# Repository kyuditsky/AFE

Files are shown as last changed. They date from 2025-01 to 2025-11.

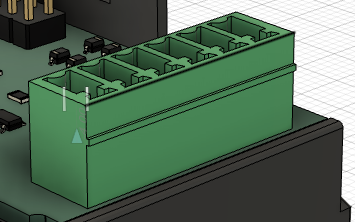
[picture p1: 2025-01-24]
images/Fusion/connector 2025-01-24 at 3.18.13 PM.png

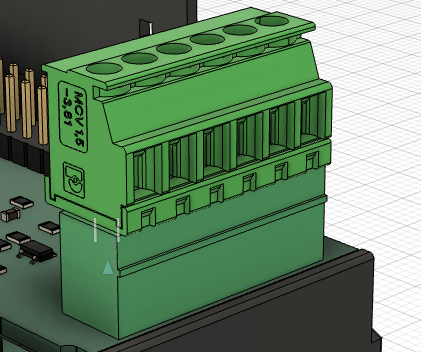
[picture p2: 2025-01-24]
images/Fusion/connector 2025-01-24 at 3.18.21 PM.png

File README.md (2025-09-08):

AFE 230V 16A

Phoenix Contact
BC Modular Housing

AFE 230v_16a buildnotes
addendums at bottom

1/14/25

***

https://media.digikey.com/pdf/data%20sheets/phoenix%20contact%20pdfs/bc_series_installation_component_housing.pdf

***

***

https://github.com/erichelgeson/Kicad-STM32
add legacy symbols:
symbol editor > File > import

manage symbols > migrate

***

BC71,6 OT-U11

i/o
---
MSTBVA_2,5_2-G-5,08		#LPC 2,5/2-ST-5,08	plug 16A / 320V
				#1792757		12A / will actually fit
				#MVSTBW 2,5/ 2-ST-5,08
j1	VO_pn
j2	K_io
j3	I_pn

MCV_1,5_6-G-3.81
j4	DGND
	3v3
	A0
	A1
	A2
	D0

footprints
TSOT-23-5	opamps
SOT-23		regulator
SOIC-7		optocoupler
SOIC-8		currentsensee

A5?		#A2
3v3in?

***
1/15/25
Blackpill STM32 will be on separate daughterboard

added HBUS connector to schema

***
HBUS-B SET BK - Protective cap
2278173
***

Spec:
Contact 1..4	power
contact 5..16	signal
Air clearances and creepage distances
... to the DIN rail At least 0.23 mm
... between one another At least 0.13 mm
... between power and signal At least 0.8 mm
Current carrying capacity for each contact
3 A, maximum total current 25 A

***
1/16/25

generated BOM from schema
refined layout and i/o port locations

request to swap A2 to A0 and slide down accordingly
	basically current on the left, voltage on right
	of J4

***
1/23/25

Housing:

HBUS 71,6-16P-1S BK - DIN rail bus connectors	2896296		#digikey 10 instock - 33.54

full set
BC 71,6-SKT-U11-7035+4SPTA6 - Housing set	1456985		#larger space on PCB2-8
								#11mm connector space on PCB1

Base:
BC 71,6 UT HBUS BK - Mounting base housing	2896267		#8.53

upperhousing UT11
BC 71,6 OT U11 KMGY - Upper housing part	2896050		#5.66

housing cover:
BC 71,6 DKL S TRANS - Housing cover		2896128		#4.93

inter-PCB connection:

ESW-106-12-G-D		6 pos, 11.05mm above pcb, gold plated, double row (12pos total)
			2.54 pitch, THT

2.54 pin header		underside of connecting pcb
			
	11.05mm + 2.54mm = 	13.59mm stack height
				perfect stack from pcb1 to pcb4

***
1/24/25

added copper pours from current i/o to U5

blackpill pinout in PCBnew appears incorrect to documentation

footprint matches:
	https://uglyduck.vajn.icu/STM32_Pills/BlackPill_STM32F103_Pinout.jpg

current blackpill:
	https://cdn-shop.adafruit.com/970x728/4877-03.jpg

updated with:
	https://github.com/MSZ98/Blackpill-KiCad-library

STEP files imported into Fusion

	MCV_1,5_6-G-3.81 	&	MCVR 1,5/ 6-ST-3,81
	1803468				1827169
		will not work, move socket towards pcb edge

	MSTBVA_2,5_2-G-5,08	&	MVSTBW 2,5/ 2-ST-5,08
	1755736				1792757
		will NOT work
		connectors should rotate
		and new connector should be chosen

Fillets on main PCB edges are only needed if filler plugs are to be used

SPTAF 1/ 5-3, 5-IL	supplied with housing kit, 11mm deep
	16A 160V

1862275
SPTAF 1/ 2-5,0-IL	2 terminal
	16A 320V	made to order	in stock at mouser
			IL vs EL

SPTAF 1/ 4-5,0-EL	4 terminal	#use 6 terminal for signal i/o
1862437			

AC inputs should be at least 2.5mm wire

***
https://electronics.stackexchange.com/questions/645255/4-layer-board-clearance-and-stack-up-for-230v

creepage / clearance

remove gnd plane from around I_inputs & Vp/n

***
1/27/25

SPTAF 1/ 6-5,0-EL
1862453

2202302 upper housing 11,11,22,00	restricted availability

in order to use SPTA-THR 2,5/ 6-5,0 P26		#for 12 awg wire AC inputs
need to swtich to UT22 upperhousing

1071206
SPTA-THR 1,5/ 6-5,08 R56	#might work, wire size 16awg
				#nonstocked at mouser
				#instock at digikey

***
02/02/25

Mouser Order sent			order#273566739

ordered two MKDSN 1.5/2-HT		1985849		rated 13A/320v
	for Ki/o
AC inputs: MKDSN 2.5/3-5.08-BK		1800882		
	(2.5/6 out of stock)
Signal Out: MKDS 1.5/6			1715190

********

02/06/25

revisiting pcb2-8
	& headers between
	see 01/23/25		#ESW-106-12-G-D

JLCPCB standard pcb thickness = 1.6mm

space between each:

pcb1-2	3,55mm
pcb2-3	3,45
pcb3-4	3,45
pcb4-5	3.45		#if blackpill is socketed, void pcb5-8
pcb5-6	3,45
pcb6-7	0,95
pcb7-8	-0.3		#pcb7&8 cannot co-exist
pcb8-9	1.25		#pcb9 replaces fitted cover

>>>pcb1 edge dimensions are incorrect
	edge cutouts in middle are too deep
	HBUS connector is in the wrong spot
>>fixed hbus placement
	did not change edgecuts
	current edge cut and drawing differ 0,45mm	
		#radius of curve 1,2mm but edges are 0,75mm offset
		#hbus location callout uses the 0,75mm line

considering shifting intrapcb connector to the left	#implemented
	reasoning: allows for pcb 2 to be installed (cutout is close to mounting fin ~1.5mm)

****
02/16/25

added pcb5-7 with kludge and copper pours
added kludge to other pcbs

added silkscreen on pcb9

****

02/27/25

PCBs arrived, Parts arrived
putting it together:

pcb8 does not fully lock into bottom case
	top base needs a support remove as well
	*use pcb7 instead (may still need to remove support
	pcb8 gnd plane net is wrong

overall, edgecuts are correct

c1-2 are 0402?		#my bad
	footprint is 0603

the intrapcb connectors looks good
make cutout in pcb2,3 larger, but fits for now

U4, solidstate relay, just barely fits under pcb2

typical female 2.54mm header, from pcb1 to pcb3, stacks directly underpcb3

	pcb3-pcb5 approximately the same thing
	could probably use pcb1, 3, & 5 for a 3 board arrangement

****
05/05/25 - meeting

issues soldering the ground plane pads - with thermal relief

plan to design to pick and place, still jlcpcb?
	mitigate some of the issues possibly due to soldering

testing feels like a waste of time, i dont always know what im looking at

dont have a good grasp of the details of the scope

single ended two op amps, gnd and point
	A0 and A1 subtract one from another to get ------

differential has 3 op amp
	does the subtraction

single
a0 ref to gnd
a1 ref to gnd
	note divider from 3V to GND to give 1.5v at input buffer

diff r19 r21 should be 500, r20 1k
r22 r23 dnp

everycircuit - simulator

testing setup >>
single ended (two opamp)
	wavegen 1 & gnd to V0p & V0n
	scope 1+ to A0			1+ 
	scope 1- to A1			scope 1- to dgnd
	3v3V+ to 3v3
	gnd to DGND
waveform passed through without power to board
	1.5v observed at r35/r36

differential
	wavegen 1 & gnd to V0p & V0n
	scope 1+ to A0
	scope 1- to dgnd
	3v3V+ to 3v3
	gnd to DGND
	
	0.6v observed at r35/r36
***	
	r22/r23 should be DNP
	r19/r21 should be 500ohm

****
updated guidance:
Focus on single ended:

	two sides are separate paths, test 1 path at a time
	
	V0p - wave to A0 - scope
	scope1- to dgnd

	V0n - wave to A1 - scope
	scope1- to dgnd

	(need to check for 1.5V at r15/r17; r16/18)

07/09/25

differential board, 3 opamps
	depopped r22, r21
	lifted a trace near r22, 
		determined iron too hot with narrower tip

Lifted R19 pads while desoldering
	buss wired from R20 to U1-4 & R22
		cut old R22 trace to A0
		R19 is now on R22 pads
		replaced to 510ohm
R21 now 510ohm
R20 in place at 1k

hot glue placed over cut A0 trace
	(exposed gnd plane)

*******
08/13/25 10:00a

identify and order just the differential parts
	to be tested via V0/V1_sense on HBUS footprint
	using the digilent waveform gen

initial DNP:	
	r1-12 	voltage dividers 
	d1-4	zener diodes
	c1 c2	capacitors	sized up to 0603

V0_sense starts: 	
	r13 	499k ohm 	#consider a 0ohm resistor
	c1	1nf
	r15 	20k (to 3vREF)	#Voltage divider to non-inverting input U1
	r17	20k (to gnd)
	r19	510		#feedback R
	
	r24	1k		#buffer to non-inverting U3
	r27	1k		#buffer to 1.5vREF	(r35&r36 20k divider)

V1_sense starts:
	r14 	499k ohm 	#consider a 0ohm resistor
	c2	1nf
	r16 	20k (to 3vREF)	#Voltage divider to non-inverting input U2
	r18	20k (to gnd)
	r21	510		#feedback R
	
	r25	1k		#buffer to inverting U3
	r26	1k		#U3 feedback

common components:

	U1-3	AD8528		#opamps		TSOT23-5
	d1-4	pdz36b		#36v zener diodes, order but dnp

	r20	1k		#ties both sides together
	r35	20k		#1.5vREF
	r36	20k		#1.5vREF
	U7	REF3030		#3V regulator	SOT23

	r39	0		#gnd to dgnd
	C5,6,10	0.1uF		#filtercaps

notes:
	look at r20 net, should it be connected directly to output of u1
		#sent to nathan
		confirms r20 should bridge U1 out to U2 out
		updated PCBnew

	populate PCB a few components at a time & test
		looking at you 1.5vREF

AFE_230v_16a rev.2 aug25
	changelog
	
	changed r20 to u1 & u2 outputs
	added thermal relief to D1 D2 earth connections
	added thermal relief to I_p & I_n fill zones
	rotated U4 to keep traces on F.cu
	added AVDD indicator LEDs to main pcb

2pm
lets order the updated pcb and mouser components by end of day

	look into jlcpcb pick and place and smaller components (0402)

AFE_diff_schematic
	focus on just the differential section
		using 0402 components
****
new plan (again)
	we are ordering a new pcb (because of R20)
	pick and place the components on the new pcb (adjust footprints accordingly)
		keeping all R footprints for now, all C footprints are 0603

	U1-3, U6, LEDs, & R29 non- placeable
	D1-4 are extended ($3.00 per extended component type)
	U7 is extended, opted out

	ordering 5 boards, populating 2 ($0.75 more to populate 5 as opposed to 2)
				and rev1 single end works without revision
				but. lets keep some blank boards
	16.17 for pcb+pcba
	9.97 shipping
	-9.00 coupon
	total: 18.05

***

08/18/25
	plan to order female pin headers from Adafruit

	leave off R34 from auto-populating
		or add 0 ohm jumper

	need to organize spreadsheets better

****
09/08/25

ordered more microhook test leads

looking over mouser order

	AC signal inputs - 1
	Signal Outputs - 1
	K i/o - 2

	opamps - 10
	U4 Relay - 1
	U7 3v ref - 5
	U5 current sense - 2
	R29 big R - 4
	
	pcb4 elevated socket - 2

R20 could have been rerouted without a via to B.Cu
removed thermal relief from Ip,In

dont auto-populate r30,r31 (only pop for opamp current sensing with r29)

test before populating r1-12 (voltage dividers)

r13,14, r22,23 will need hand populating (extended componenets)
	#should not have popped r22,r23, but will test waveform thru A0,A1
5v,3v3 LED hand pop

header pins as needed
	V1/V0 test points
	DGND > D0 header
		dgnd, 3v, A0,A1,A2,D0

3v3, 5v LED test good

3v3 supply, no opamps
	3.317v at 3v3
	2.997v at 3vref
	1.483v at 1.5vref

#same divider but different nets?
#1.5vref and r15/r17 & r16/r18

power looks good, continueing to add opamps

Should not have popped r22,r23 for differential setup, but will test waveform thru A0,A1
	V0_sense thru to A0
	V1_sense thru to A1
		both test good without power to board, no offset

		with 3v3 power to board, look good, adds a 1.46v(A0) & 1.47v(A1) offset
			with or without waveform input (5v amplitude)
			scope range 1v/div

going to remove r22,r23
	r22,23 depopped without trouble

3v3 supply, opamps installed
r27, 1.5vref = 1.497v
3v0ref = 3.0v
3v3 = 3.317v
1.5vref = 1.497v (r35/r36)

power still looks good

3v3 to board

W1 to V0_sense
W2 to V1_sense

1+ to A0
1- to dgnd

no longer the 1.5v offset
	output (A0) looks promising, especially with Sine wave inputs
	scope range needs to be dialed down to 100mV/div or less

can add 
	Vin dividers (r1-12)
	input/signal I/O
	blackpill header
	Ki/o relay
& option for either 
		current sense IC (depop r30,31)
		or R29 & opamp

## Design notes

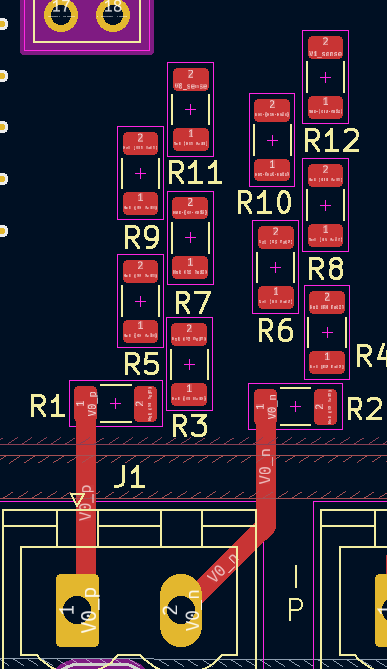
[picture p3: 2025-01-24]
images/screenshots/Screenshot 2025-01-22 at 2.59.26 PM.png

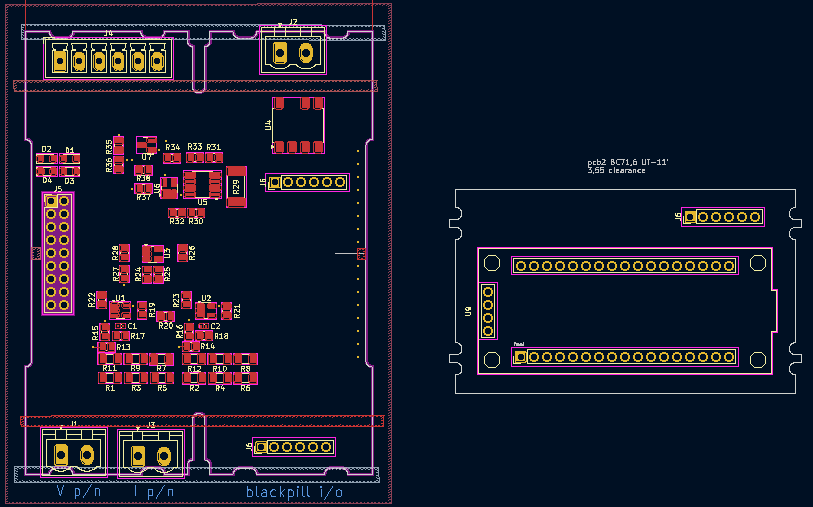
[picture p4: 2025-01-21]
images/adjust_layout_2025-01-21 at 1.56.01 PM.png

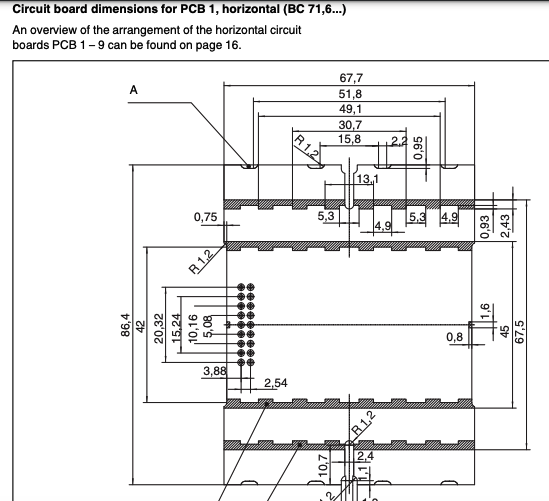
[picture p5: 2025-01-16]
images/HBUS_/Screenshot 2025-01-16 at 11.58.03 AM.png

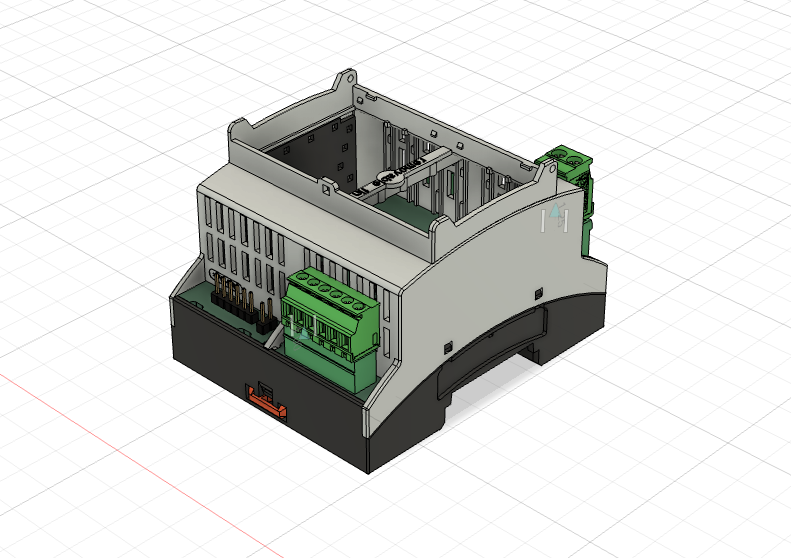
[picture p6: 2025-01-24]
images/Fusion/wide 2025-01-24 at 4.25.02 PM.png

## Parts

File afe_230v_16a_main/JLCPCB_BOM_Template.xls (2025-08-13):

Comment | Designator | Footprint | JLCPCB Part#(optional)
100uF | C1 | CASE-B_3528 | C16133
100nF | C2, C9, C10 | 0603 | C14663
300KΩ | R4, R7 | 0603 | C23024
15KΩ | R5, R6 | 0603_R | C22809
100KΩ | R1, R3 | 0603_R | C25803
10uF | C3-5 | 1206_C | C13585
100Ω | R2 | 0603_R | C22775
1N4148WS | D1 | SOD-323 | C2128
LM358DR2G | U1 | SOIC-8_150mil | C7950
HT7550-1 | VR1 | SOT-89(SOT-89-3) | C16106

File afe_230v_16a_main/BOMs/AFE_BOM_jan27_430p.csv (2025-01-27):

AFE_230V_16A
Mouser # | Mfr. # | Manufacturer | Customer # | Description | RoHS | Lifecycle | Order Qty. | Price (USD) | Ext.: (USD)
584-AD8538AUJZ-R7 | AD8538AUJZ-REEL7 | Analog Devices Inc. | AFE_U1-3,6 | Precision Amplifiers ingle Low Power AutoZero Amp | RoHS Compliant |  | 6 | $1.99 | $7.96
250-711ELCTR25ABT | ACS711ELCTR-25AB-T | Allegro MicroSystems | afe_U5 | Board Mount Current Sensors CURRENT SENSOR WITH OVERCURRENT FAULT OUTPUT | RoHS Compliant By Exemption |  | 1 | $1.54 | $1.54
595-REF3030AIDBZR | REF3030AIDBZR | Texas Instruments | afe_U7 | Voltage References 3.0V 50ppm/DegC 50uA SOT23-3 Series A 595-REF3030AIDBZT | RoHS Compliant |  | 2 | $1.02 | $1.02
769-AQH3223A | AQH3223A | Panasonic | afe_U4 | Solid State Relays - PCB Mount AC 600 V 1.2 A Non- Zero Cross | RoHS Compliant |  | 2 | $1.94 | $1.94
187-CL05C102JB51PNC | CL05C102JB51PNC | Samsung Electro-Mechanics | afe_C1,2 | Multilayer Ceramic Capacitors MLCC - SMD/SMT 1nF C0G 50V 0402 Auto grade | RoHS Compliant | New Product | 4 | $0.10 | $0.20
771-PDZ36B-T/R | PDZ36B,115 | Nexperia | afe_D1-4 ! | Zener Diodes PDZ36B/SOD323/SOD2 | RoHS Compliant |  | 8 | $0.15 | $0.60
652-CHP1206AFX-6803L | CHP1206AFX-6803ELF | Bourns | afe_r1-12 | Thick Film Resistors - SMD ResHighPowerA 1206 68R 1% 3/4W TC100 | RoHS Compliant By Exemption |  | 24 | $0.202 | $2.42
667-ERJ-P06F4993V | ERJ-P06F4993V | Panasonic | afe_R13,14 | Thick Film Resistors - SMD 0805 499Kohms 0.5W 1% AEC-Q200 | RoHS Compliant By Exemption |  | 4 | $0.18 | $0.36
660-SG73P2ATTD2002F | SG73P2ATTD2002F | KOA Speer | afe_R15-18,35,36 | Thick Film Resistors - SMD 0.5W 20Kohm 1% AEC-Q200 | RoHS Compliant By Exemption |  | 12 | $0.17 | $1.02
71-RCC08050000Z0EA | RCC08050000Z0EA | Vishay | afe_R38_dnp | Thick Film Resistors - SMD Zero ohm Jumper | RoHS Compliant By Exemption |  | 7 | $0.13 | $0.39
667-ERJ-P06F1001V | ERJ-P06F1001V | Panasonic | afe_R30-34,37 | Thick Film Resistors - SMD 0805 1Kohms 0.5W 1% AEC-Q200 | RoHS Compliant By Exemption |  | 12 | $0.062 | $0.74
667-ERJ-P06F33R2V | ERJ-P06F33R2V | Panasonic | afe_R22,23 | Thick Film Resistors - SMD 0805 33.2ohms 0.5W 1% AEC-Q200 | RoHS Compliant By Exemption |  | 4 | $0.18 | $0.36
 |  |  |  |  | RoHS Compliant
 |  |  |  |  | RoHS Compliant
279-TLRP3A20WR005FTE | TLRP3A20WR005FTE | TE Connectivity | afe_R29 | Current Sense Resistors - SMD TLRP 2512 2.0W R005 1% 75PPM 4K RL |  |  | 1 | $0.66 | $0.66
651-2896050 | 2896050 | Phoenix Contact |  | Upper housing |  |  | 2
651-2896267 | 2896267 | Phoenix Contact |  | Housing base |  |  | 2
651-2896128 | 2896128 | Phoenix Contact |  | Housing cover |  |  | 1
651-2896209 | 2896209 | Phoenix Contact |  | Filler Plug |  |  | 2
200-ESW10612GD | ESW-106-12-G-D | Samtec | afe_pcb4_conn | Elevated socket strip |  |  | 2
855-M20-9774046 | M20-9774046 | Darwin |  | Pin header strip |  |  | 4
649-76308-120LF | 76308-120LF | Amphenol FCI |  | 1x20 pinheaded socket (black pill) |  |  | 5
81-GCM188R71C104KA7J | GCM188R71C104KA37J | Murata | afe_C4-10 | 0.1uf filter caps |  |  | 8
651-1800882 | 1800882 |  | AC input_alts | MKDSN 2,5/ 3-5,08 |  |  | 4
651-1989405 | 1989405 |  | AC inputs | MKDSN 2,5/ 6-5,08 |  |  | 0
651-1715190 | 1715190 |  | Signal | MKDS 1,5/ 6 |  |  | 2
604-APT2012LZGCK | APT2012LZGCK |  | afe_led1,2 | LED |  |  | 4
279-CRG0805J2K2 | CRG0805J2K2 |  | afe_led_r | LED_r |  |  | 4

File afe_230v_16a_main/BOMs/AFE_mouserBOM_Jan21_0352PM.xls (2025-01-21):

AFE_230V_16A
Mouser # | Mfr. # | Manufacturer | Customer # | Description | RoHS | Lifecycle | Order Qty. | Price (USD) | Ext.: (USD)
584-AD8538AUJZ-R7 | AD8538AUJZ-REEL7 | Analog Devices Inc. | AFE_U1-3,6 | Precision Amplifiers ingle Low Power AutoZero Amp | RoHS Compliant |  | 4 | $1.99 | $7.96
250-711ELCTR25ABT | ACS711ELCTR-25AB-T | Allegro MicroSystems | afe_U5 | Board Mount Current Sensors CURRENT SENSOR WITH OVERCURRENT FAULT OUTPUT | RoHS Compliant By Exemption |  | 1 | $1.54 | $1.54
595-REF3030AIDBZR | REF3030AIDBZR | Texas Instruments | afe_U7 | Voltage References 3.0V 50ppm/DegC 50uA SOT23-3 Series A 595-REF3030AIDBZT | RoHS Compliant |  | 1 | $1.02 | $1.02
769-AQH3223A | AQH3223A | Panasonic | afe_U4 | Solid State Relays - PCB Mount AC 600 V 1.2 A Non- Zero Cross | RoHS Compliant |  | 1 | $1.94 | $1.94
187-CL05C102JB51PNC | CL05C102JB51PNC | Samsung Electro-Mechanics | afe_C1,2 | Multilayer Ceramic Capacitors MLCC - SMD/SMT 1nF C0G 50V 0402 Auto grade | RoHS Compliant | New Product | 2 | $0.10 | $0.20
771-PDZ36B8115 | PDZ3.6B,115 | Nexperia | afe_D1-4_! | Zener Diodes PDZ3.6B/SOD323/SOD2 | RoHS Compliant |  | 4 | $0.10 | $0.40
771-PDZ36B-T/R | PDZ36B,115 | Nexperia | afe_D1-4 ! | Zener Diodes PDZ36B/SOD323/SOD2 | RoHS Compliant |  | 4 | $0.15 | $0.60
652-CHP1206AFX-6803L | CHP1206AFX-6803ELF | Bourns | afe_r1-12 | Thick Film Resistors - SMD ResHighPowerA 1206 68R 1% 3/4W TC100 | RoHS Compliant By Exemption |  | 12 | $0.202 | $2.42
667-ERJ-P06F4993V | ERJ-P06F4993V | Panasonic | afe_R13,14 | Thick Film Resistors - SMD 0805 499Kohms 0.5W 1% AEC-Q200 | RoHS Compliant By Exemption |  | 2 | $0.18 | $0.36
660-SG73P2ATTD2002F | SG73P2ATTD2002F | KOA Speer | afe_R15-18,35,36 | Thick Film Resistors - SMD 0.5W 20Kohm 1% AEC-Q200 | RoHS Compliant By Exemption |  | 6 | $0.17 | $1.02
71-RCC08050000Z0EA | RCC08050000Z0EA | Vishay | afe_R38_dnp | Thick Film Resistors - SMD Zero ohm Jumper | RoHS Compliant By Exemption |  | 3 | $0.13 | $0.39
667-ERJ-P06F1001V | ERJ-P06F1001V | Panasonic | afe_R30-34,37 | Thick Film Resistors - SMD 0805 1Kohms 0.5W 1% AEC-Q200 | RoHS Compliant By Exemption |  | 12 | $0.062 | $0.74
667-ERJ-P06F33R2V | ERJ-P06F33R2V | Panasonic | afe_R22,23 | Thick Film Resistors - SMD 0805 33.2ohms 0.5W 1% AEC-Q200 | RoHS Compliant By Exemption |  | 2 | $0.18 | $0.36
651-1755736 | 1755736 | Phoenix Contact | afe_J1-3 | Pluggable Terminal Blocks 2 Pos 5.08mm pitch Through Hole Header | RoHS Compliant |  | 3 | $0.64 | $1.92
651-1803468 | 1803468 | Phoenix Contact | afe_J4 | Pluggable Terminal Blocks 6 Pos 3.81mm pitch Through Hole Header | RoHS Compliant |  | 1 | $2.39 | $2.39
279-TLRP3A20WR005FTE | TLRP3A20WR005FTE | TE Connectivity | afe_R29 | Current Sense Resistors - SMD TLRP 2512 2.0W R005 1% 75PPM 4K RL |  |  | 1 | $0.66 | $0.66

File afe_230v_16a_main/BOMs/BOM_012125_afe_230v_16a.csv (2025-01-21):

Reference | Value | Datasheet | Footprint | Qty | DNP
C1,C2 | 1nF | ~ | Capacitor_SMD:C_0402_1005Metric | 2
J1,J2,J3 | MSTBVA_2,5_2-G-5,08 |  |  | 3
D1,D2,D3,D4 | PDZ36B | ~ | Diode_SMD:D_SOD-323F | 4
J4 | MCV 1,5/ 6-G-3,81 | ~ | Connector_Phoenix_MC:PhoenixContact_MCV_1,5_6-G-3.81_1x06_P3.81mm_Vertical | 1
J5 |  | HBUS 71,6-16P-1S BK / 2896296 | Connector_PinHeader_2.54mm:PinHeader_2x09_P2.54mm_Vertical | 1
P1 | 06-14-03_rectifier |  |  | 1
R1,R2,R3,R4,R5,R6,R7,R8,R9,R10,R11,R12 | 680K | ~ | Resistor_SMD:R_1206_3216Metric | 12
R13,R14 | 499K | ~ | Resistor_SMD:R_0805_2012Metric | 2
R15,R16,R17,R18,R35,R36 | 20K | ~ | Resistor_SMD:R_0805_2012Metric | 6
R19,R21 | 0K | ~ | Resistor_SMD:R_0805_2012Metric | 2
R20,R24,R25,R26,R27,R28 | 1K_dnp | ~ | Resistor_SMD:R_0805_2012Metric | 6 | DNP
R22,R23 | 33R2 | ~ | Resistor_SMD:R_0805_2012Metric | 2
R29 | 0R005 | ~ | Resistor_SMD:R_2512_6332Metric_Pad1.40x3.35mm_HandSolder | 1
R30,R31,R32,R33,R34,R37 | 1KR | ~ | Resistor_SMD:R_0805_2012Metric | 6
R38 | 0K_dnp | ~ | Resistor_SMD:R_0805_2012Metric | 1 | DNP
U1 | AD8538 | https://www.analog.com/media/en/technical-documentation/data-sheets/AD8538_8539.pdf | Package_TO_SOT_SMD:TSOT-23-5 | 1
U2 | AD8538 | https://www.analog.com/media/en/technical-documentation/data-sheets/AD8538_8539.pdf | Package_TO_SOT_SMD:TSOT-23-5 | 1
U3,U6 | AD8538_dnp | https://www.analog.com/media/en/technical-documentation/data-sheets/AD8538_8539.pdf | Package_TO_SOT_SMD:TSOT-23-5 | 2 | DNP
U4 | AQH3223A | https://mediap.industry.panasonic.eu/assets/imported/industrial.panasonic.com/ac/cdn/e/control/relay/solid-state/catalog/semi_eng_aqh.pdf | Package_SO:SSO-7-8_6.4x9.78mm_P2.54mm | 1
U5 | ACS711xLCTR-25AB | http://www.allegromicro.com/~/Media/Files/Datasheets/ACS711-Datasheet.ashx | Package_SO:SOIC-8_3.9x4.9mm_P1.27mm | 1
U7 | REF3030 | http://www.ti.com/lit/ds/symlink/ref3033.pdf | Package_TO_SOT_SMD:SOT-23 | 1

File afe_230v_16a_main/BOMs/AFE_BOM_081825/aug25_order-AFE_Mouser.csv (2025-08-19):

AFE_230V_16A
Mouser # | Mfr. # | Manufacturer | Customer # | Qty. | Hand | JLC_mount | Description | RoHS | Lifecycle | Order Qty. | Price (USD) | Ext.: (USD)
584-AD8538AUJZ-R7 | AD8538AUJZ-REEL7 | Analog Devices Inc. | AFE_U1-3,6 | 10 |  |  | Precision Amplifiers ingle Low Power AutoZero Amp | RoHS Compliant |  | 6 | $1.99 | $7.96
250-711ELCTR25ABT | ACS711ELCTR-25AB-T | Allegro MicroSystems | afe_U5 | 2 |  |  | Board Mount Current Sensors CURRENT SENSOR WITH OVERCURRENT FAULT OUTPUT | RoHS Compliant By Exemption |  | 1 | $1.54 | $1.54
595-REF3030AIDBZR | REF3030AIDBZR | Texas Instruments | afe_U7 | 4 |  |  | Voltage References 3.0V 50ppm/DegC 50uA SOT23-3 Series A 595-REF3030AIDBZT | RoHS Compliant |  | 2 | $1.02 | $1.02
769-AQH3223A | AQH3223A | Panasonic | afe_U4 | 1 |  |  | Solid State Relays - PCB Mount AC 600 V 1.2 A Non- Zero Cross | RoHS Compliant |  | 2 | $1.94 | $1.94
187-CL05C102JB51PNC | CL05C102JB51PNC | Samsung Electro-Mechanics | afe_C1,2 | 0 |  | Y | Multilayer Ceramic Capacitors MLCC - SMD/SMT 1nF C0G 50V 0402 Auto grade | RoHS Compliant | New Product | 4 | $0.10 | $0.20
81-GCM188R71C104KA7J | GCM188R71C104KA37J | Murata | afe_C4-10 | 0 |  | Y | 0.1uf filter caps 0402 |  |  | 8
771-PDZ36B-T/R | PDZ36B,115 | Nexperia | afe_D1-4 ! | 8 |  | Y | Zener Diodes PDZ36B/SOD323/SOD2 | RoHS Compliant |  | 8 | $0.15 | $0.60
652-CHP1206AFX-6803L | CHP1206AFX-6803ELF | Bourns | afe_r1-12 | 30 |  |  | Thick Film Resistors - SMD ResHighPowerA 1206 68R 1% 3/4W TC100 | RoHS Compliant By Exemption |  | 24 | $0.20 | $2.42
667-ERJ-P06F4993V | ERJ-P06F4993V | Panasonic | afe_R13,14 | 10 |  |  | Thick Film Resistors - SMD 0805 499Kohms 0.5W 1% AEC-Q200 | RoHS Compliant By Exemption |  | 4 | $0.18 | $0.36
660-SG73P2ATTD2002F | SG73P2ATTD2002F | KOA Speer | afe_R15-18,35,36 | 0 | 18 | Y | Thick Film Resistors - SMD 0.5W 20Kohm 1% AEC-Q200 | RoHS Compliant By Exemption |  | 12 | $0.17 | $1.02
71-RCC08050000Z0EA | RCC08050000Z0EA | Vishay | afe_R38, R39 | 0 | 18 | Y | Thick Film Resistors - SMD Zero ohm Jumper | RoHS Compliant By Exemption |  | 7 | $0.13 | $0.39
667-ERJ-P06F1001V | ERJ-P06F1001V | Panasonic | afe_R30-34,37 | 0 | 18 | Y | Thick Film Resistors - SMD 0805 1Kohms 0.5W 1% AEC-Q200 | RoHS Compliant By Exemption |  | 12 | $0.06 | $0.74
667-ERJ-P06F33R2V | ERJ-P06F33R2V | Panasonic | afe_R22,23 | 6 |  |  | Thick Film Resistors - SMD 0805 33.2ohms 0.5W 1% AEC-Q200 | RoHS Compliant By Exemption |  | 4 | $0.18 | $0.36
 |  |  | R40,41 | 20 |  | Y | Thick Film Resistors - SMD 0805 2.2kohms | RoHS Compliant
 |  |  | R19,21 | 10 |  | Y | Thick Film Resistors - SMD 0805 510ohms
 |  |  |  |  |  |  |  | RoHS Compliant
279-TLRP3A20WR005FTE | TLRP3A20WR005FTE | TE Connectivity | afe_R29 | 4 |  |  | Current Sense Resistors - SMD TLRP 2512 2.0W R005 1% 75PPM 4K RL |  |  | 1 | $0.66 | $0.66
651-2896050 | 2896050 | Phoenix Contact |  | 0 |  |  | Upper housing |  |  | 2
651-2896267 | 2896267 | Phoenix Contact |  | 0 |  |  | Housing base |  |  | 2
651-2896128 | 2896128 | Phoenix Contact |  | 0 |  |  | Housing cover |  |  | 1
651-2896209 | 2896209 | Phoenix Contact |  | 0 |  |  | Filler Plug |  |  | 2
200-ESW10612GD | ESW-106-12-G-D | Samtec | afe_pcb4_conn | 4 |  |  | Elevated socket strip |  |  | 2
855-M20-9774046 | M20-9774046 | Darwin |  | 0 |  |  | Pin header strip |  |  | 4
649-76308-120LF | 76308-120LF | Amphenol FCI |  |  |  |  | Female header strip - 20 POS |  |  |  | 3.71
604-APT2012LZGCK | APT2012LZGCK |  | afe_led1,2 | 10 |  |  | Single Color LEDs Single Color LEDs 2.0X1.2MM LOW CRNT |  |  | 4
279-CRG0805J2K2 | CRG0805J2K2 |  | afe_led_r | 0 |  | Y | LED_r |  |  | 4
651-1800882 | 1800882 |  | AC input_alts | 4 |  |  | MKDSN 2,5/ 3-5,08 |  |  | 4
651-1989405 | 1989405 |  | AC inputs | 0 |  |  | MKDSN 2,5/ 6-5,08 |  |  | 0
651-1715190 | 1715190 |  | Signal | 2 |  |  | MKDS 1,5/ 6 |  |  | 2

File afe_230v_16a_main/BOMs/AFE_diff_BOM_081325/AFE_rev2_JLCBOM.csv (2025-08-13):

Value | Designator | Footprint | Jlcpcb part#
499kΩ | R13, R14 | 0805
1nF | C1, C2 | 0603
0.1uF | C4, C5, C6, C10 | 0603
680kΩ | R1-12 | 1206
20kΩ | R15, R16, R17, R18, R35, R36 | 0805
510Ω | R19, R21 | 0805
1kΩ | R20, R24-27, R30-34, R37 | 0805
PDZ36B | D1-4 | D_SOD-323
REF3030 | U7 | SOT23
0Ω | R38, R39 | 0805
2.2kΩ | R40, R41 | 0805

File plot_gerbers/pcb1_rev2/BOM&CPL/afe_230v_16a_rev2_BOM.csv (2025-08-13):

Designator | Val | Footprint
C1 | 1nF | C_0603_1608Metric_Pad1.08x0.95mm_HandSolder
C2 | 1nF | C_0603_1608Metric_Pad1.08x0.95mm_HandSolder
C4 | 0.1uF | C_0603_1608Metric_Pad1.08x0.95mm_HandSolder
C5 | 0.1uF | C_0603_1608Metric_Pad1.08x0.95mm_HandSolder
C6 | 0.1uF | C_0603_1608Metric_Pad1.08x0.95mm_HandSolder
C10 | 0.1uF | C_0603_1608Metric_Pad1.08x0.95mm_HandSolder
D1 | PDZ36B | D_SOD-323_HandSoldering
D2 | PDZ36B | D_SOD-323_HandSoldering
D3 | PDZ36B | D_SOD-323_HandSoldering
D4 | PDZ36B | D_SOD-323_HandSoldering
R15 | 20K | R_0805_2012Metric
R16 | 20K | R_0805_2012Metric
R17 | 20K | R_0805_2012Metric
R18 | 20K | R_0805_2012Metric
R19 | 510 | R_0805_2012Metric
R20 | 1K | R_0805_2012Metric
R21 | 510 | R_0805_2012Metric
R24 | 1K | R_0805_2012Metric
R25 | 1K | R_0805_2012Metric
R26 | 1K | R_0805_2012Metric
R27 | 1K | R_0805_2012Metric
R28 | 1K | R_0805_2012Metric
R30 | 1K | R_0805_2012Metric
R31 | 1K | R_0805_2012Metric
R32 | 1K | R_0805_2012Metric
R33 | 1K | R_0805_2012Metric
R34 | 1K | R_0805_2012Metric
R35 | 20K | R_0805_2012Metric
R36 | 20K | R_0805_2012Metric
R37 | 1K | R_0805_2012Metric
R38 | 0 | R_0805_2012Metric
R39 | 0 | R_0805_2012Metric
R40 | 2.2k | R_0805_2012Metric
R41 | 2.2k | R_0805_2012Metric
U7 | REF3030 | SOT-23

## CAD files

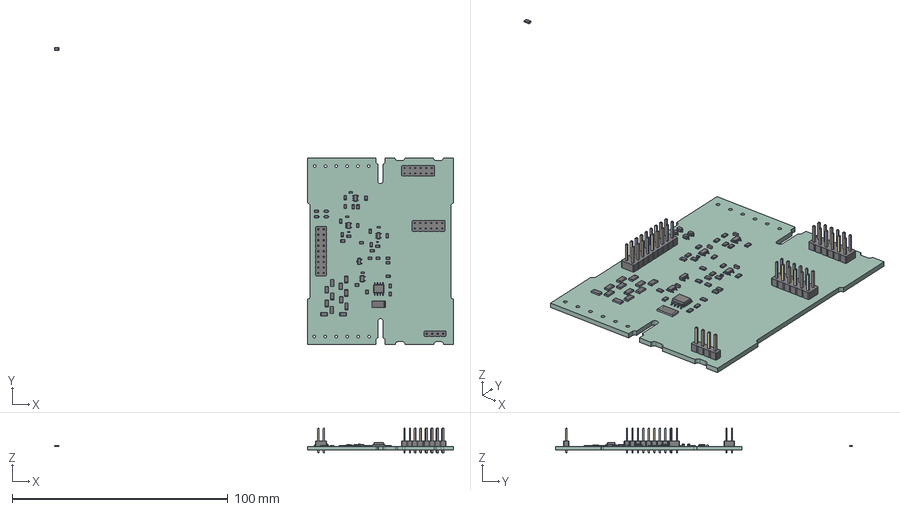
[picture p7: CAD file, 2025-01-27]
STEP/afe_230v_16a_6.step
184.9 x 137.5 x 11.5 mm
R_0805_2012Metric x 26
R_1206_3216Metric x 12
D_SOD_323 x 4
C_0402_1005Metric x 2
C_0603_1608Metric x 4
PinHeader_1x04_P254mm_Vertical
SOT_23
TSOT_23_5 x 4
SOIC_8_39x49mm_P127mm
PinHeader_2x06_P254mm_Vertical x 2
R_2512_6332Metric
PinHeader_2x09_P254mm_Vertical
_autosave-afe_230v_16a_PCB

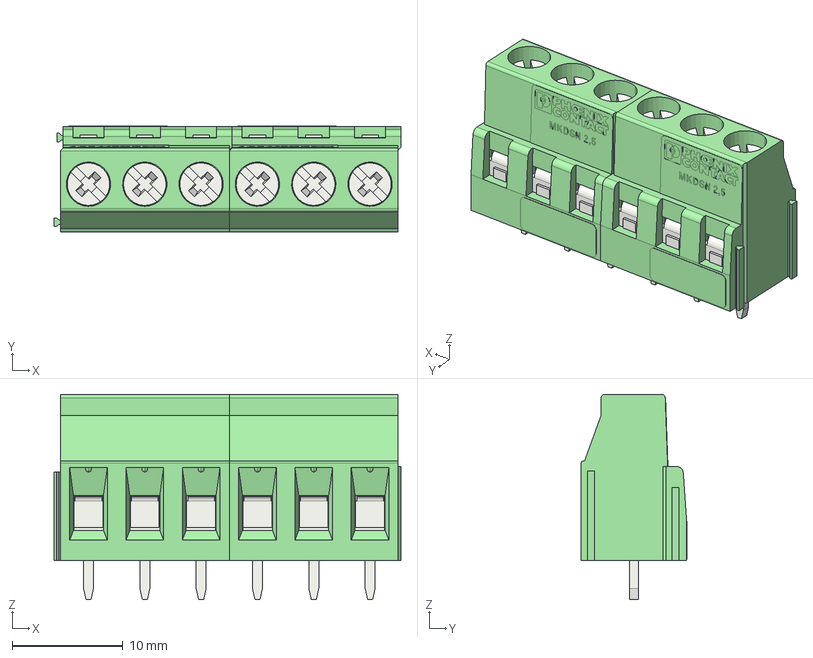
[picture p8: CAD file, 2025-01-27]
STEP/pxc_1989405_01_01_MKDSN-2-5-6-5-08_3D.stp
31.3 x 9.53 x 18.5 mm

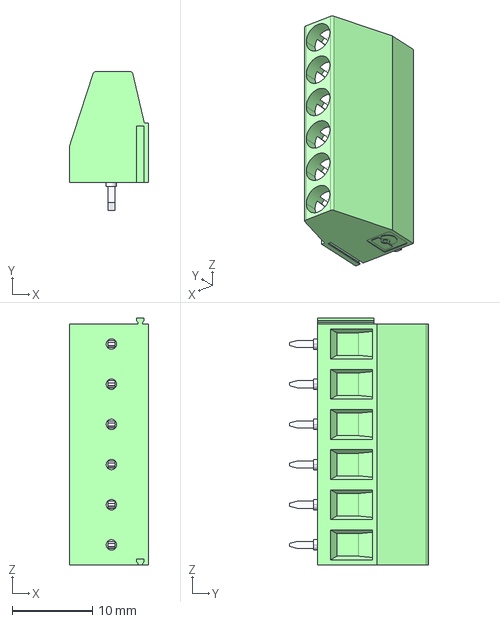
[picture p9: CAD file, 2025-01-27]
STEP/pxc_1715190_02_MKDS-1-5-6_3D.stp
9.80 x 17.3 x 30.7 mm

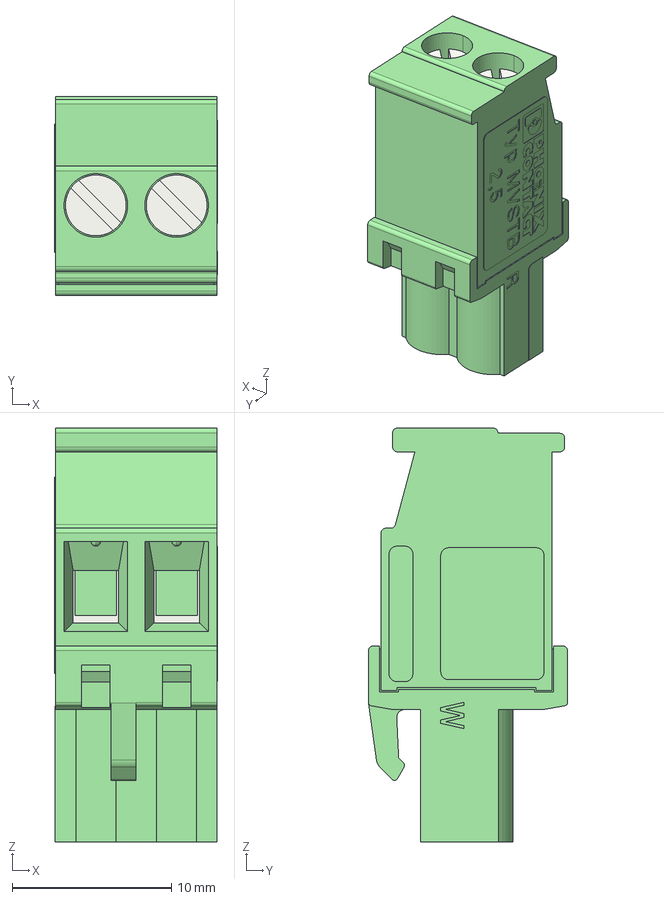
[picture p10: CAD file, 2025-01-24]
STEP/pxc_1792249_04_MVSTBR-2-5-2-ST-5-08_3D.stp
10.3 x 12.5 x 26.0 mm

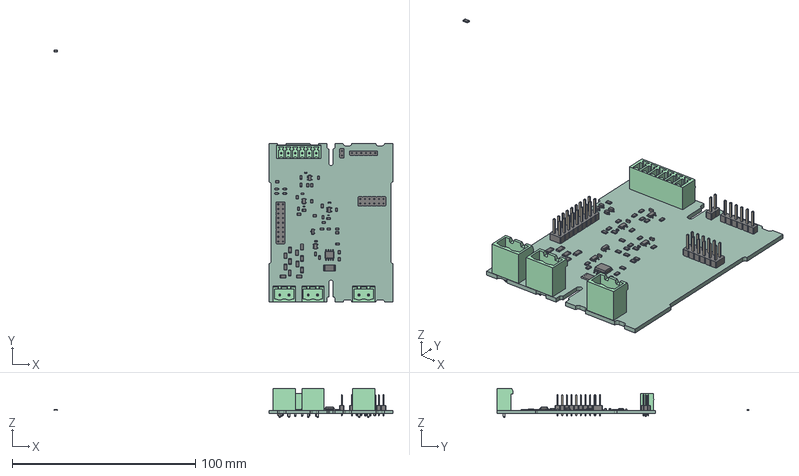
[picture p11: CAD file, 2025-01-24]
STEP/afe_230v_16a_2.step
184.9 x 137.5 x 16.0 mm
R_0805_2012Metric x 27
R_1206_3216Metric x 12
PinHeader_1x06_P254mm_Vertical
D_SOD_323 x 4
C_0402_1005Metric x 2
C_0603_1608Metric x 4
MSTBVA_01x02_G_5_08mm x 3
SOT_23
TSOT_23_5 x 4
SOIC_8_39x49mm_P127mm
MCV_01x06_G_3_81mm
PinHeader_2x06_P254mm_Vertical
R_2512_6332Metric
PinHeader_1x02_P254mm_Vertical
PinHeader_2x09_P254mm_Vertical
_autosave-afe_230v_16a_PCB

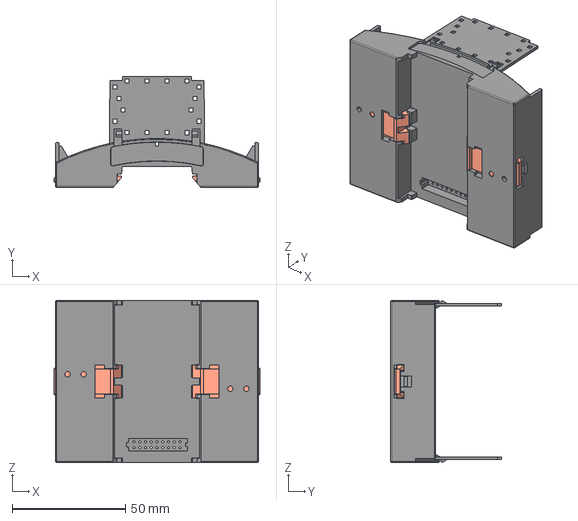
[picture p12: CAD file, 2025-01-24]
STEP/pxc_2896267_05_04_BC-71-6-UT-HBUS-BK_3D.stp
91.0 x 48.9 x 71.6 mm
BC_71.6_GEH-UT_HBUS_H.Select__00377778
Fussriegel_14.4_L30_Sperr_H.Select__00370451 x 2

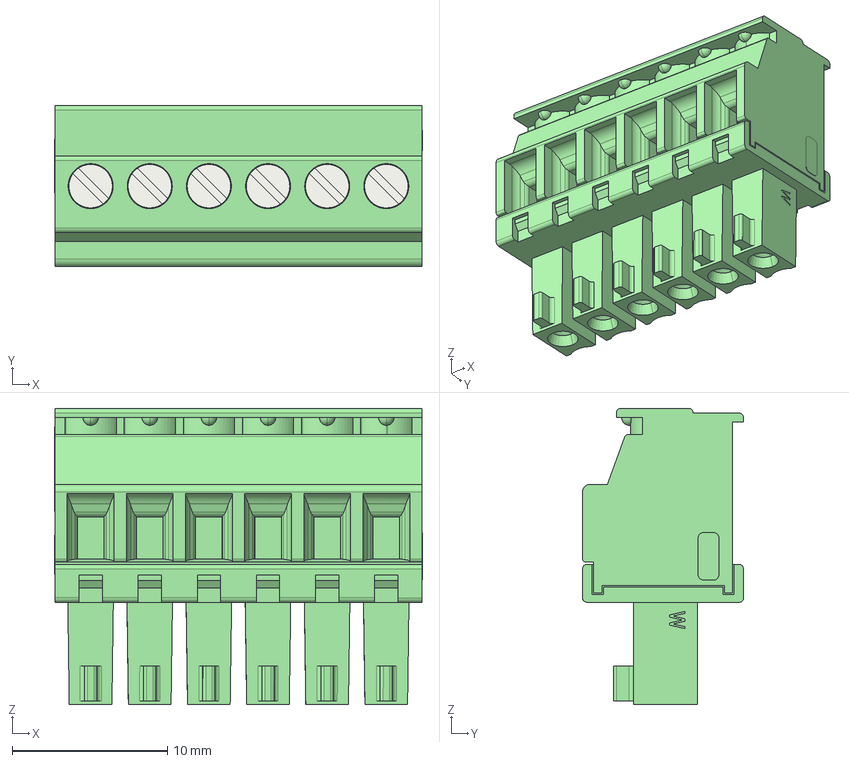
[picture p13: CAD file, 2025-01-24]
STEP/pxc_1827169_03_00_MCVR-1-5-6-ST-3-81_3D.stp
23.7 x 10.4 x 19.1 mm

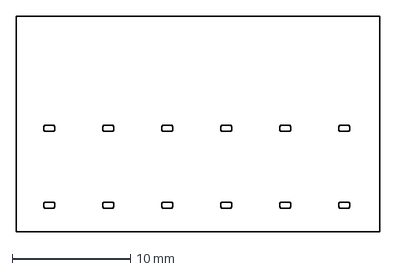
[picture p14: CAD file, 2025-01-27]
STEP/1366008_foot.dxf
30.8 x 18.3 mm

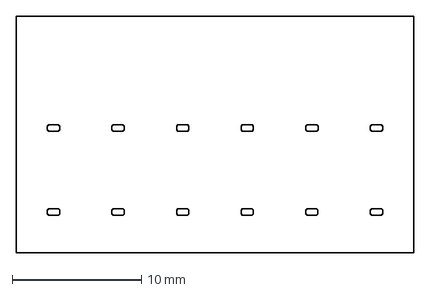
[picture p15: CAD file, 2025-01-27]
STEP/1366008.dxf
30.8 x 18.3 mm

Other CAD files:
STEP/afe_230v_16a_5.step
STEP/afe_230v_16a_4.step
STEP/pxc_1792757_03_MVSTBW-2-5-2-ST-5-08_3D.stp
STEP/afe_230v_16a_3.step

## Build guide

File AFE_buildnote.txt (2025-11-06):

AFE 230v_16a buildnotes
addendums at bottom

1/14/25

***

https://media.digikey.com/pdf/data%20sheets/phoenix%20contact%20pdfs/bc_series_installation_component_housing.pdf

***

***

https://github.com/erichelgeson/Kicad-STM32
add legacy symbols:
symbol editor > File > import

manage symbols > migrate

***

BC71,6 OT-U11

i/o
---
MSTBVA_2,5_2-G-5,08		#LPC 2,5/2-ST-5,08	plug 16A / 320V
				#1792757		12A / will actually fit
				#MVSTBW 2,5/ 2-ST-5,08
j1	VO_pn
j2	K_io
j3	I_pn

MCV_1,5_6-G-3.81
j4	DGND
	3v3
	A0
	A1
	A2
	D0

footprints
TSOT-23-5	opamps
SOT-23		regulator
SOIC-7		optocoupler
SOIC-8		currentsensee

A5?		#A2
3v3in?

***
1/15/25
Blackpill STM32 will be on separate daughterboard

added HBUS connector to schema

***
HBUS-B SET BK - Protective cap
2278173
***

Spec:
Contact 1..4	power
contact 5..16	signal
Air clearances and creepage distances
... to the DIN rail At least 0.23 mm
... between one another At least 0.13 mm
... between power and signal At least 0.8 mm
Current carrying capacity for each contact
3 A, maximum total current 25 A

***
1/16/25

generated BOM from schema
refined layout and i/o port locations

request to swap A2 to A0 and slide down accordingly
	basically current on the left, voltage on right
	of J4

***
1/23/25

Housing:

HBUS 71,6-16P-1S BK - DIN rail bus connectors	2896296		#digikey 10 instock - 33.54

full set
BC 71,6-SKT-U11-7035+4SPTA6 - Housing set	1456985		#larger space on PCB2-8
								#11mm connector space on PCB1

Base:
BC 71,6 UT HBUS BK - Mounting base housing	2896267		#8.53

upperhousing UT11
BC 71,6 OT U11 KMGY - Upper housing part	2896050		#5.66

housing cover:
BC 71,6 DKL S TRANS - Housing cover		2896128		#4.93

inter-PCB connection:

ESW-106-12-G-D		6 pos, 11.05mm above pcb, gold plated, double row (12pos total)
			2.54 pitch, THT

2.54 pin header		underside of connecting pcb
			
	11.05mm + 2.54mm = 	13.59mm stack height
				perfect stack from pcb1 to pcb4

***
1/24/25

added copper pours from current i/o to U5

blackpill pinout in PCBnew appears incorrect to documentation

footprint matches:
	https://uglyduck.vajn.icu/STM32_Pills/BlackPill_STM32F103_Pinout.jpg

current blackpill:
	https://cdn-shop.adafruit.com/970x728/4877-03.jpg

updated with:
	https://github.com/MSZ98/Blackpill-KiCad-library

STEP files imported into Fusion

	MCV_1,5_6-G-3.81 	&	MCVR 1,5/ 6-ST-3,81
	1803468				1827169
		will not work, move socket towards pcb edge

	MSTBVA_2,5_2-G-5,08	&	MVSTBW 2,5/ 2-ST-5,08
	1755736				1792757
		will NOT work
		connectors should rotate
		and new connector should be chosen

Fillets on main PCB edges are only needed if filler plugs are to be used

SPTAF 1/ 5-3, 5-IL	supplied with housing kit, 11mm deep
	16A 160V

1862275
SPTAF 1/ 2-5,0-IL	2 terminal
	16A 320V	made to order	in stock at mouser
			IL vs EL

SPTAF 1/ 4-5,0-EL	4 terminal	#use 6 terminal for signal i/o
1862437			

AC inputs should be at least 2.5mm wire

***
https://electronics.stackexchange.com/questions/645255/4-layer-board-clearance-and-stack-up-for-230v

creepage / clearance

remove gnd plane from around I_inputs & Vp/n

***
1/27/25

SPTAF 1/ 6-5,0-EL
1862453

2202302 upper housing 11,11,22,00	restricted availability

in order to use SPTA-THR 2,5/ 6-5,0 P26		#for 12 awg wire AC inputs
need to swtich to UT22 upperhousing

1071206
SPTA-THR 1,5/ 6-5,08 R56	#might work, wire size 16awg
				#nonstocked at mouser
				#instock at digikey

***
02/02/25

Mouser Order sent			order#273566739

ordered two MKDSN 1.5/2-HT		1985849		rated 13A/320v
	for Ki/o
AC inputs: MKDSN 2.5/3-5.08-BK		1800882		
	(2.5/6 out of stock)
Signal Out: MKDS 1.5/6			1715190

********

02/06/25

revisiting pcb2-8
	& headers between
	see 01/23/25		#ESW-106-12-G-D

JLCPCB standard pcb thickness = 1.6mm

space between each:

pcb1-2	3,55mm
pcb2-3	3,45
pcb3-4	3,45
pcb4-5	3.45		#if blackpill is socketed, void pcb5-8
pcb5-6	3,45
pcb6-7	0,95
pcb7-8	-0.3		#pcb7&8 cannot co-exist
pcb8-9	1.25		#pcb9 replaces fitted cover

>>>pcb1 edge dimensions are incorrect
	edge cutouts in middle are too deep
	HBUS connector is in the wrong spot
>>fixed hbus placement
	did not change edgecuts
	current edge cut and drawing differ 0,45mm	
		#radius of curve 1,2mm but edges are 0,75mm offset
		#hbus location callout uses the 0,75mm line

considering shifting intrapcb connector to the left	#implemented
	reasoning: allows for pcb 2 to be installed (cutout is close to mounting fin ~1.5mm)

****
02/16/25

added pcb5-7 with kludge and copper pours
added kludge to other pcbs

added silkscreen on pcb9

****

02/27/25

PCBs arrived, Parts arrived
putting it together:

pcb8 does not fully lock into bottom case
	top base needs a support remove as well
	*use pcb7 instead (may still need to remove support
	pcb8 gnd plane net is wrong

overall, edgecuts are correct

c1-2 are 0402?		#my bad
	footprint is 0603

the intrapcb connectors looks good
make cutout in pcb2,3 larger, but fits for now

U4, solidstate relay, just barely fits under pcb2

typical female 2.54mm header, from pcb1 to pcb3, stacks directly underpcb3

	pcb3-pcb5 approximately the same thing
	could probably use pcb1, 3, & 5 for a 3 board arrangement

****
05/05/25 - meeting

issues soldering the ground plane pads - with thermal relief

plan to design to pick and place, still jlcpcb?
	mitigate some of the issues possibly due to soldering

testing feels like a waste of time, i dont always know what im looking at

dont have a good grasp of the details of the scope

single ended two op amps, gnd and point
	A0 and A1 subtract one from another to get ------

differential has 3 op amp
	does the subtraction

single
a0 ref to gnd
a1 ref to gnd
	note divider from 3V to GND to give 1.5v at input buffer

diff r19 r21 should be 500, r20 1k
r22 r23 dnp

everycircuit - simulator

testing setup >>
single ended (two opamp)
	wavegen 1 & gnd to V0p & V0n
	scope 1+ to A0			1+ 
	scope 1- to A1			scope 1- to dgnd
	3v3V+ to 3v3
	gnd to DGND
waveform passed through without power to board
	1.5v observed at r35/r36

differential
	wavegen 1 & gnd to V0p & V0n
	scope 1+ to A0
	scope 1- to dgnd
	3v3V+ to 3v3
	gnd to DGND
	
	0.6v observed at r35/r36
***	
	r22/r23 should be DNP
	r19/r21 should be 500ohm

****
updated guidance:
Focus on single ended:

	two sides are separate paths, test 1 path at a time
	
	V0p - wave to A0 - scope
	scope1- to dgnd

	V0n - wave to A1 - scope
	scope1- to dgnd

	(need to check for 1.5V at r15/r17; r16/18)

07/09/25

differential board, 3 opamps
	depopped r22, r21
	lifted a trace near r22, 
		determined iron too hot with narrower tip

Lifted R19 pads while desoldering
	buss wired from R20 to U1-4 & R22
		cut old R22 trace to A0
		R19 is now on R22 pads
		replaced to 510ohm
R21 now 510ohm
R20 in place at 1k

hot glue placed over cut A0 trace
	(exposed gnd plane)

*******
08/13/25 10:00a

identify and order just the differential parts
	to be tested via V0/V1_sense on HBUS footprint
	using the digilent waveform gen

initial DNP:	
	r1-12 	voltage dividers 
	d1-4	zener diodes
	c1 c2	capacitors	sized up to 0603

V0_sense starts: 	
	r13 	499k ohm 	#consider a 0ohm resistor
	c1	1nf
	r15 	20k (to 3vREF)	#Voltage divider to non-inverting input U1
	r17	20k (to gnd)
	r19	510		#feedback R
	
	r24	1k		#buffer to non-inverting U3
	r27	1k		#buffer to 1.5vREF	(r35&r36 20k divider)

V1_sense starts:
	r14 	499k ohm 	#consider a 0ohm resistor
	c2	1nf
	r16 	20k (to 3vREF)	#Voltage divider to non-inverting input U2
	r18	20k (to gnd)
	r21	510		#feedback R
	
	r25	1k		#buffer to inverting U3
	r26	1k		#U3 feedback

common components:

	U1-3	AD8528		#opamps		TSOT23-5
	d1-4	pdz36b		#36v zener diodes, order but dnp

	r20	1k		#ties both sides together
	r35	20k		#1.5vREF
	r36	20k		#1.5vREF
	U7	REF3030		#3V regulator	SOT23

	r39	0		#gnd to dgnd
	C5,6,10	0.1uF		#filtercaps

notes:
	look at r20 net, should it be connected directly to output of u1
		#sent to nathan
		confirms r20 should bridge U1 out to U2 out
		updated PCBnew

	populate PCB a few components at a time & test
		looking at you 1.5vREF

AFE_230v_16a rev.2 aug25
	changelog
	
	changed r20 to u1 & u2 outputs
	added thermal relief to D1 D2 earth connections
	added thermal relief to I_p & I_n fill zones
	rotated U4 to keep traces on F.cu
	added AVDD indicator LEDs to main pcb

2pm
lets order the updated pcb and mouser components by end of day

	look into jlcpcb pick and place and smaller components (0402)

AFE_diff_schematic
	focus on just the differential section
		using 0402 components
****
new plan (again)
	we are ordering a new pcb (because of R20)
	pick and place the components on the new pcb (adjust footprints accordingly)
		keeping all R footprints for now, all C footprints are 0603

	U1-3, U6, LEDs, & R29 non- placeable
	D1-4 are extended ($3.00 per extended component type)
	U7 is extended, opted out

	ordering 5 boards, populating 2 ($0.75 more to populate 5 as opposed to 2)
				and rev1 single end works without revision
				but. lets keep some blank boards
	16.17 for pcb+pcba
	9.97 shipping
	-9.00 coupon
	total: 18.05

***

08/18/25
	plan to order female pin headers from Adafruit

	leave off R34 from auto-populating
		or add 0 ohm jumper

	need to organize spreadsheets better

****
09/08/25

ordered more microhook test leads

looking over mouser order

	AC signal inputs - 1
	Signal Outputs - 1
	K i/o - 2

	opamps - 10
	U4 Relay - 1
	U7 3v ref - 5
	U5 current sense - 2
	R29 big R - 4
	
	pcb4 elevated socket - 2

R20 could have been rerouted without a via to B.Cu
removed thermal relief from Ip,In

dont auto-populate r30,r31 (only pop for opamp current sensing with r29)

test before populating r1-12 (voltage dividers)

r13,14, r22,23 will need hand populating (extended componenets)
	#should not have popped r22,r23, but will test waveform thru A0,A1
5v,3v3 LED hand pop

header pins as needed
	V1/V0 test points
	DGND > D0 header
		dgnd, 3v, A0,A1,A2,D0

3v3, 5v LED test good

3v3 supply, no opamps
	3.317v at 3v3
	2.997v at 3vref
	1.483v at 1.5vref

#same divider but different nets?
#1.5vref and r15/r17 & r16/r18

power looks good, continueing to add opamps

Should not have popped r22,r23 for differential setup, but will test waveform thru A0,A1
	V0_sense thru to A0
	V1_sense thru to A1
		both test good without power to board, no offset

		with 3v3 power to board, look good, adds a 1.46v(A0) & 1.47v(A1) offset
			with or without waveform input (5v amplitude)
			scope range 1v/div

going to remove r22,r23
	r22,23 depopped without trouble

3v3 supply, opamps installed
r27, 1.5vref = 1.497v
3v0ref = 3.0v
3v3 = 3.317v
1.5vref = 1.497v (r35/r36)

power still looks good

3v3 to board

W1 to V0_sense
W2 to V1_sense

1+ to A0
1- to dgnd

no longer the 1.5v offset
	output (A0) looks promising, especially with Sine wave inputs
	scope range needs to be dialed down to 100mV/div or less

can add 
	Vin dividers (r1-12)
	input/signal I/O
	blackpill header
	Ki/o relay
& option for either 
		current sense IC (depop r30,31)
		or R29 & opamp
	
****

10/21/25
	check both sides of diff input with W1, S1+ > A0

R19,R21, on Rev2 autopop board are 510ohm
	*single ended should be 0ohm

goals:

	*done
	single end autopop board and set up as single ended AFE W/ current sense IC
		pop:
			R22, R23, R13, R14
			U1, U2, 
			U7		#needed for 3v0
			U5		#current sense IC
			R19,R21		#swap to 0ohm jumper
			D5,D6		#AVDD LED's
		*depop:	
			R20
			#R30,R31	#redundant disconnect
			R32,R34		#disconnects other architecture
			R37		#to disconnect 1.5v from A2
			#R38		#connects A2 to I0_sense (pin13 HBUS)
			R24-R27		#removed, left R26,R28
			R19,R21		#repop with 0ohm

	relays - depop from rev.01 (both boards, low priority)

	check on hand qty of Vin array R1-12 (need 24)
		mouser order #276278869 states 38 ordered (aug25)

	**
	diff Rev2 board:
		pop:
			R29
			R1-12
			U6	#op-amp for Isense
			U4	relay
		
	*Done, needs tested

inventory left:

	opamps - 4
	led - 	6
	3v0 ref- 3
	r1-12 - 14
	current sense ic- 0 (used on rev2 single end)
	zener diodes - 8
	r29- 3
	zero ohm jump - 14

****
10/24/25

testing single end AFE, Rev2.0
	power:
	LEDs good
	3v3 opamp power good
	3v0 rectifier good
	1v5 divider good

scope 1+ on A0
scope 2+ on A1
	no input: 1v5 bias, I think
	wave1 > V0_sense
	wave2 > V1_sense
scope 1,2- > gnd

wavegens outputing 5v 10kHz sine wave
	scopes reading 174mV peak to peak
	A0 & A1 slightly out of phase

shift wave1,2 to V0p & V0n
	peak2peak = ~15mV	#makes sense, 
				#thats what the input voltage divider is for

now checking against single end rev1.0		#this board was in decent shape
	
	1v5 bias
	20mV p2p
	looks good

double checking rev2
	1v5 bias
	20mV p2p
	looks the same, 
		#tho phase is almost 180* out now
		#pert sure thats as it should be

**possible issue between DGND and Earth
	keep eye on it

diff rev2
	wave1,2 to V0p,V0n
	scope1+ to A0
	looks great, the input signals add amplitude to the output
	0.825v bias	5V 10kHz inputs
	42mV p2p

note: always opt for the 5pcb build out

mouser: 37270215	38.23
	ordered i/o jacks, 1 set housing

		cost of 1 housing:	15.24
			upper:		6.33
			lower:		8.91	

***
11/03/25
2nd monitor set up over electronics bench
mouser parts came in

taking a look at differtial again
	bias was around 0.8v
	5v input at both v_sense and separately at Vin
and that was to be expected

check single ends, expected similar bias (0.8v)
	checked all lines, bias at consistant ~1.5v

cross checked rev01 single ended to rev2, same results
	plan to add i/o to rev2 boards and send out
	keep rev1 single end board for rPi testing (functionally equivalent to rev2)
	see if we'vve got parts on hand to handbuild another rev2 diff board
		consider improving layout

***
11/06/25
14 0ohm jump on hand

r42,r43 popped x2
	hbus jumpers

added i/o to both rev2 boards

packing for shipment
	(2)	BC 71.6, UT22 housing upper + base - 2896267, 2896050		
	(1)	BC 71.6 Hinged Clear Cover - 2896128
	(1)	BC 71.6 plastic Cover Plate - 2896128 (same mfr#)
	(2)	PCB9 AFE Cover Plate (1 installed)
	(1)	Diff rev2.0, populated
	(1)	Single rev2.0 populated
	(1)	pcb4 blackpill daughter, populated
	(2)	20 pin F.header
	(2)	6 pin male header
	(2)	UT22 Cover Cap (11.1mm depth, 36.6mm width) - 2896209
	(2)	pcbpack 2-8 (1-pcb4 smd populated)
	(1)	pcb1 rev1.0 blank
	(1)	pcb1 rev2.0 blank

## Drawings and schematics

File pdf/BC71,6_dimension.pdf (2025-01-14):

30,7
15,8

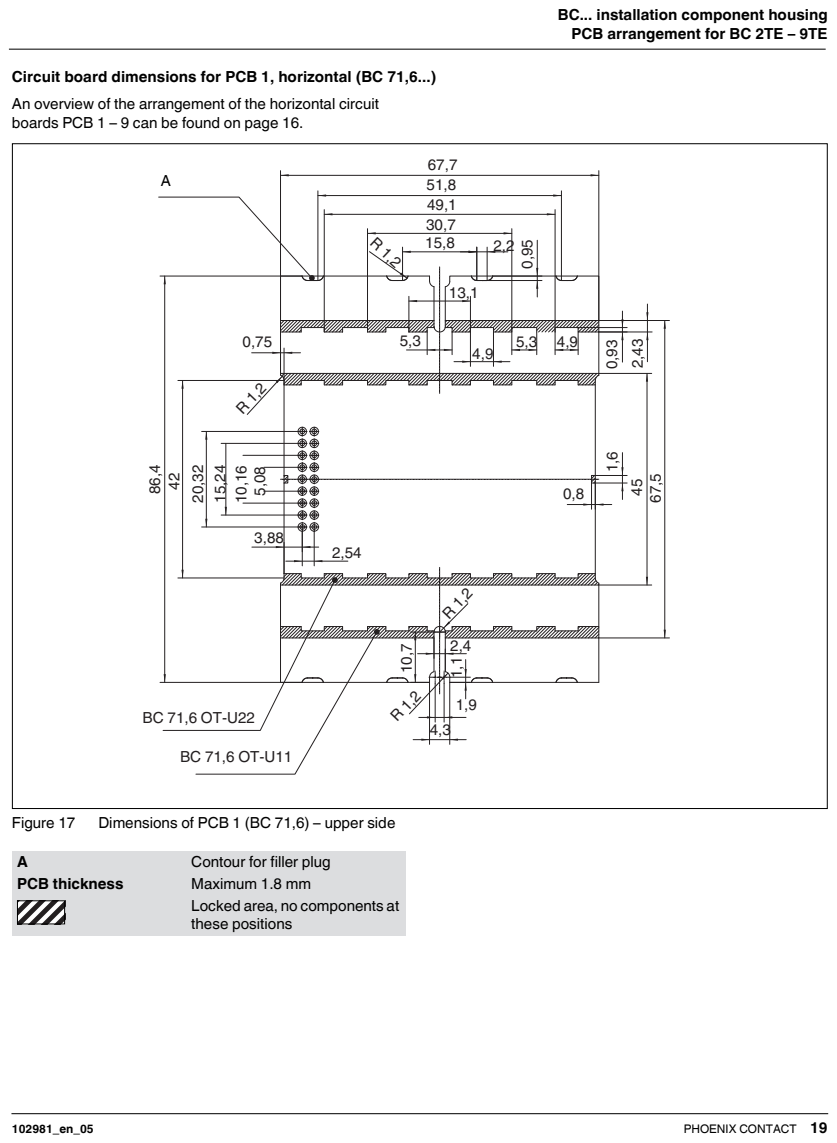
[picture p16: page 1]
PHOENIX CONTACT; Figure 17; Dimensions of PCB 1 (BC 71,6) – upper side; PCB thickness; Maximum 1.8 mm

BC... installation component housing
PCB arrangement for BC 2TE – 9TE

Circuit board dimensions for PCB 1, horizontal (BC 71,6...)

An overview of the arrangement of the horizontal circuit
boards PCB 1 – 9 can be found on page 16.

A Contour for filler plug

Locked area, no components at
these positions

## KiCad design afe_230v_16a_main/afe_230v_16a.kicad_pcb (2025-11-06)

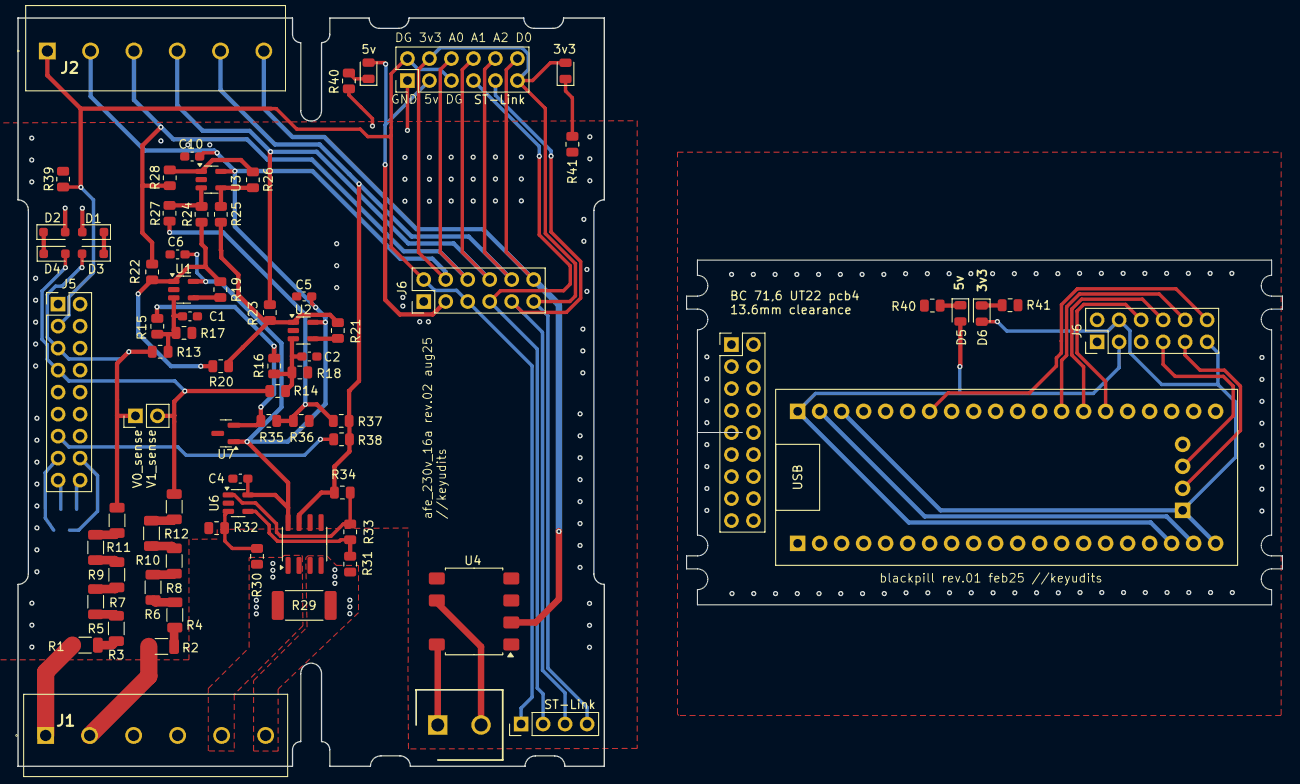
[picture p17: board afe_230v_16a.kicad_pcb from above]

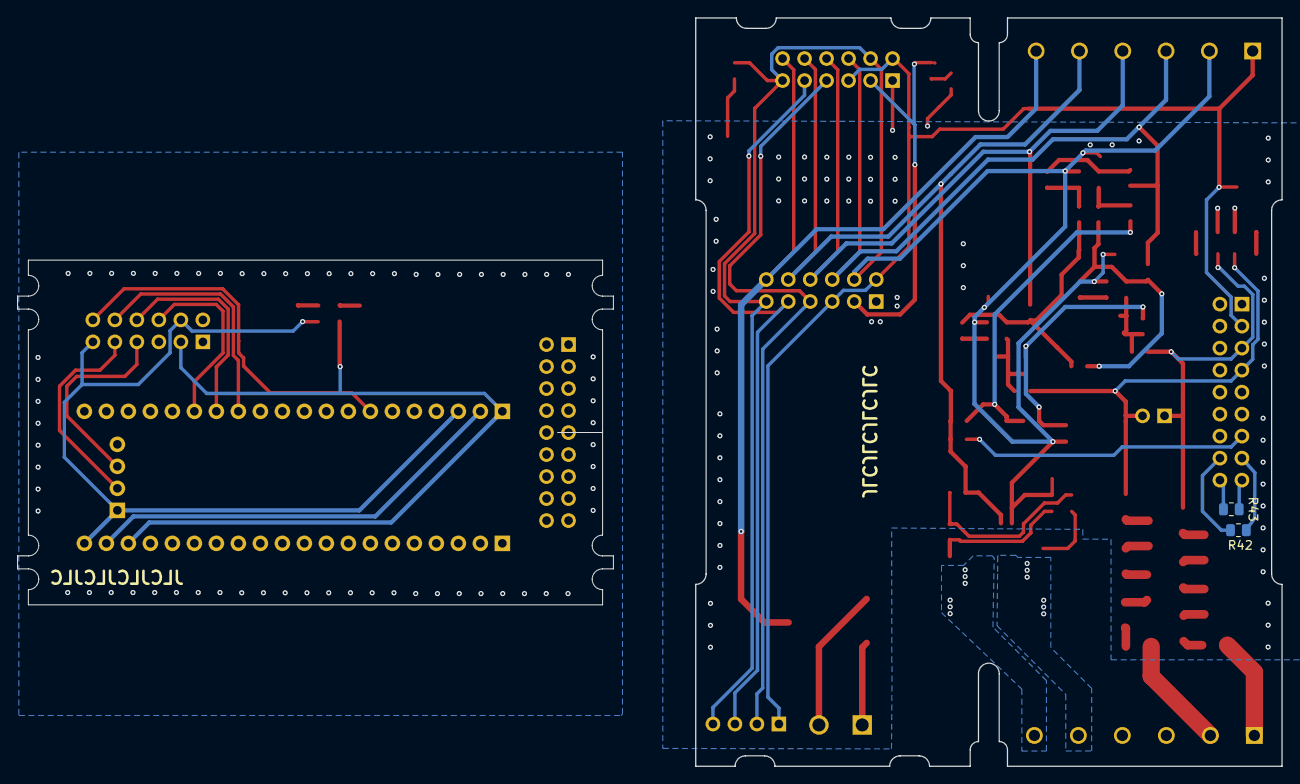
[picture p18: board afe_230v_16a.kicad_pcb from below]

Board: 2 copper layers, 67.7 x 86.4 mm, 76 parts (2 on the bottom side), 61 nets.

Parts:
3v3, 5v: LED; LED_0805_2012Metric
C1, C2: 1nF; C_0603_1608Metric_Pad1.08x0.95mm_HandSolder
C4, C5, C6, C10: 0.1uF; C_0603_1608Metric_Pad1.08x0.95mm_HandSolder
D1, D2, D3, D4: PDZ36B; D_SOD-323_HandSoldering
D5, D6: LED; LED_0805_2012Metric
J1: MKDSN 2,5/ 6-5,08; 1989405
J2: MKDS 1,5/ 6; 1715190
J5, J5#2: HBUS16; PinHeader_2x09_P2.54mm_Vertical
J6, J6#2, J6#3: pinheader_2x6_socket; PinHeader_2x06_P2.54mm_Vertical
J**: SHDR2W130P0X500_1X2_1000X810X1000P; 1985849_SHDR2W130P0X500_1X2_1000X810X1000P
R1, R2, R3, R4, R5, R6, R7, R8, R9, R10, R11, R12: 680K; R_1206_3216Metric
R13, R14: 499K; R_0805_2012Metric
R15, R16, R17, R18, R35, R36: 20K; R_0805_2012Metric
R19, R21: 0K; R_0805_2012Metric
R20, R24, R25, R26, R27, R28: 1K_dnp; R_0805_2012Metric
R22, R23: 33R2; R_0805_2012Metric
R29: 0R005; R_2512_6332Metric_Pad1.40x3.35mm_HandSolder
R30, R31, R32, R33, R34, R37: 1KR; R_0805_2012Metric
R38: 0K_dnp; R_0805_2012Metric
R39, R42, R43: 0; R_0805_2012Metric
R40, R40#2, R41, R41#2: 2.2k; R_0805_2012Metric
ST-Link: Conn_01x04_STlink_pinheader; PinHeader_1x04_P2.54mm_Vertical
U1: TSOT-23-5
U2: AD8538; TSOT-23-5
U3, U6: AD8538_dnp; TSOT-23-5
U4: AQH3223A; SSO-7-8_6.4x9.78mm_P2.54mm
U5: ACS711xLCTR-25AB; SOIC-8_3.9x4.9mm_P1.27mm
U7: REF3030; SOT-23
U10: BlackPill_F4_SWI; Blackpill_F4_SWI

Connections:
/1V5_REF: R27.2, R35.1, R36.2, R37.2
/3V0_REF: R15.2, R16.2, R35.2, U7.2 (OUT)
/3V3: 3v3.2 (A), C4.1, C5.1, C6.1, C10.1, D6.2 (A), J2.2, J6.4, J6.11, J6#2.4, J6#2.11, J6#3.4, J6#3.11, ST-Link.4, U1.5 (V+), U2.5 (V+), U3.5 (V+), U5.8 (VCC), U6.5 (V+), U7.1 (IN), U10.20 (3V3), U10.38 (3V3), U10.41 (3V3)
/5v: 5v.2 (A), D5.2 (A), J6.3, J6#2.3, J6#3.3, U10.18 (5V), U10.40 (5V)
/15a: J5.15, J5#2.15, R42.1
/15b: J5.16, J5#2.16, R42.2
/16a: J5.17, J5#2.17, R43.1
/16b: J5.18, J5#2.18, R43.2
/24V: J5.1, J5#2.1
/A0: J2.3, J6.6, J6#2.6, J6#3.6, R22.2, R28.2, U10.26 (A0)
/A1: J2.4, J6.8, J6#2.8, J6#3.8, R23.2, U10.27 (A1)
/A2: J2.5, J6.10, J6#2.10, J6#3.10, R34.2, R37.1, R38.1, U5.7 (VIOUT), U10.28 (A2)
/CAN_hi: J5.9, J5#2.9
/CAN_lo: J5.11, J5#2.11
/D0: J2.6, J6.12, J6#2.12, J6#3.12, U4.2, U10.34 (B0)
/DGND: J2.1, J5.3, J5#2.3, J6.2, J6.5, J6#2.2, J6#2.5, J6#3.2, J6#3.5, R39.2, ST-Link.1
/DIO: J6.9, J6#2.9, J6#3.9, ST-Link.3, U10.42 (SWDIO)
/I0_sense: J5.13, J5#2.13, R38.2
/I_n: J1.6, R29.2, R31.2, U5.3 (IP-), U5.4 (IP-)
/I_p: J1.5, R29.1, R30.1, U5.1 (IP+), U5.2 (IP+)
/K0_on: J5.2, J5#2.2
/K0_status: J5.6, J5#2.6
/K1_on: J5.4, J5#2.4
/K1_status: J5.8, J5#2.8
/K_i: J**.1, U4.8
/K_o: J**.2, U4.6
/SCK: J6.7, J6#2.7, J6#3.7, ST-Link.2, U10.43 (SWCLK)
/V0_n: J1.2, R2.1
/V0_p: J1.1, R1.1
/V0_sense: D3.2 (A), J5.5, J5#2.5, R11.2, R13.1
/V1_sense: D4.2 (A), J5.7, J5#2.7, R12.2, R14.1
/V2_sense: J5.10, J5#2.10
/V3_sense: J5.12, J5#2.12
/V4_sense: J5.14, J5#2.14
Earth: C1.2, C2.2, C4.2, C5.2, C6.2, C10.2, D1.2 (A), D2.2 (A), J6.1, J6#2.1, J6#3.1, R17.1, R18.1, R32.2, R36.1, R39.1, R40.1, R40#2.1, R41.1, R41#2.1, U1.2 (V-), U2.2 (V-), U3.2 (V-), U4.1, U4.3, U4.4, U5.5 (GND), U6.2 (V-), U7.3 (GND), U10.19 (G), U10.39 (G), U10.44 (GND)
unnamed: D1.1 (K), D3.1 (K)
unnamed: D2.1 (K), D4.1 (K)
unnamed: 5v.1 (K), D5.1 (K), R40.2, R40#2.2
unnamed: 3v3.1 (K), D6.1 (K), R41.2, R41#2.2
unnamed: R1.2, R3.1
unnamed: R2.2, R4.1
unnamed: R3.2, R5.1
unnamed: R4.2, R6.1
unnamed: R5.2, R7.1
unnamed: R6.2, R8.1
unnamed: R7.2, R9.1
unnamed: R8.2, R10.1
unnamed: R10.2, R12.1
unnamed: R9.2, R11.1
unnamed: R19.2, R20.1, R22.1, R24.1, U1.1
unnamed: R20.2, R21.2, R23.1, R25.1, U2.1
unnamed: R26.2, R28.1, U3.1
unnamed: R33.2, R34.1, U6.1
unnamed: C1.1, R13.2, R15.1, R17.2, U1.3 (+)
unnamed: R19.1, U1.4 (-)
unnamed: C2.1, R14.2, R16.1, R18.2, U2.3 (+)
unnamed: R21.1, U2.4 (-)
unnamed: R24.2, R27.1, U3.3 (+)
unnamed: R25.2, R26.1, U3.4 (-)
unnamed: R30.2, R32.1, U6.3 (+)
unnamed: R31.1, R33.1, U6.4 (-)

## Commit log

2025-01-14 011425 end of day
    [afe_230v_16a.kicad_pcb, afe_230v_16a.kicad_sch]
2025-01-15 updated schema
    [afe_230v_16a.kicad_pcb, afe_230v_16a.kicad_sch]
2025-01-15 began PCBA layout
    [afe_230v_16a.kicad_pcb, afe_230v_16a.kicad_sch]
2025-01-16 alternate layout
    [afe_230v_16a.kicad_pcb]
2025-01-21 added pcb2&3 board outlines, adjusted i/o
    [BOM_011625_afe_230v_16a.csv, afe_230v_16a.kicad_pcb, afe_230v_16a.kicad_sch]
2025-01-21 pleased with layout, onto wiring
    [afe_230v_16a.kicad_pcb]
2025-01-21 refined layout, added MouserBOM
    [AFE_mouserBOM_Jan21_0352PM.xls, BOM_011625_afe_230v_16a.csv, BOM_012125_afe_230v_16a.csv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]
2025-01-22 adjusted HBUS, DNP, & fixed A5toA2
    [afe_230v_16a.kicad_pcb, afe_230v_16a.kicad_sch]
2025-01-22 initial routing
    [afe_230v_16a.kicad_pcb]
2025-01-23 located daughterboard & updated connector
    [afe_230v_16a.kicad_pcb, afe_230v_16a.kicad_sch]
2025-01-24 changed BP footprint, added stlink connection, added 3d models
    [afe_230v_16a.kicad_pcb, afe_230v_16a.kicad_sch, afe_230v_16a_2.step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]
2025-01-27 swapped connectors
    [1366008.dxf, 1366008_foot.dxf, afe_230v_16a.kicad_pcb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]
2025-01-27 updated BOM
    [AFE_BOM_jan27_430p.csv]
2025-02-02 BOM ordered
2025-02-06 fixed hbus location, added bc71,6 edgecuts'
    [afe_230v_16a.kicad_pcb, afe_blackpill_pcb.kicad_pcb, bc_71,6_edgecuts.kicad_pcb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]
2025-02-06 adjusted inter-pcb-connector location, added edgecuts pcb2,3,4,8,9
    [afe_230v_16a.kicad_pcb, bc_71,6_edgecuts.kicad_pcb]
2025-02-16 refined BC71,6 edgecuts for pcb2-9
    [afe_230v_16a.kicad_pcb]
2025-02-19 added 15/16 0ohm resistors
    [afe_230v_16a.kicad_pcb, afe_230v_16a.kicad_sch]
2025-02-19 gerbers plotted, pcbs on order
    [afe_230v_16a-B_Cu.gbl, afe_230v_16a-B_Mask.gbs, afe_230v_16a-B_Paste.gbp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]
2025-08-13 changed r20 net
    [afe_230v_16a.kicad_pcb, afe_230v_16a.kicad_sch, diff_sketch.kicad_sch]
2025-08-13 adjusted PCB for rev.2 aug25
    [afe_230v_16a.kicad_pcb]
2025-08-13 added JLC BOM & CPL
    [AFE_rev2_JLCBOM.csv, JLCPCB_BOM_Template.xls, Sheet 1-AFE_BOM_jan27_430p.csv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]
2025-08-19 added and refined aug25 Mouser order
    [afe_230v_16a.kicad_pcb, aug25_order-AFE_Mouser.csv, jan25_bom-AFE_BOM_jan27_430p.csv]
2025-09-08 populated&tested rev2 differntial board
    [afe_230v_16a.kicad_pcb]
2025-11-06 updated buildnote
    [afe_230v_16a.kicad_sch]
2025-11-06 upgraded to kicad 9.0.6
    [afe_230v_16a.kicad_pcb, afe_230v_16a.kicad_sch]
